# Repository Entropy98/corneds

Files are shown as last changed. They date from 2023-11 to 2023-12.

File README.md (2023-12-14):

# Dependencies
 * PyOCD
 * Pico-SDK
 * gdb-multiarch

# Flashing
1. run `./scripts/flash.sh ./build/corneds_<side>.elf` in the firmware directory
2. Enter `target remote localhost:3333` to connect to started gdb server
**cannot connect with gdb-multiarch --pid argument due to ptrace vulnerability in system**

# To Do
## PCB

## Hardware

## Firmware
 * Tests
   * test debug_print test
     * unclear why uart isn't working

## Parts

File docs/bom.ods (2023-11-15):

Part | Quantity | Price | Total | Link | Total Cost | $30.54
Diodes | 42 | $0.05 | $2.10 | https://www.boardsource.xyz/products/diodesmd
MX Hot Swap Sockets | 42 | $0.15 | $6.30 | https://www.boardsource.xyz/products/MX_Hot_Swap_Sockets
Raspberry Pi Pico | 2 | $5.50 | $11.00 | https://www.amazon.com/Raspberry-Pi-Pico-RP2040-microcontroller/dp/B09437S9X4?th=1
TRRS Connector | 2 | $0.75 | $1.50 | https://www.boardsource.xyz/products/TRRS-connector
TRRS Cable | 1 | $8.00 | $8.00 | https://www.amazon.com/Replacement-Adapter-iPhone-Smartphone-VideoMicro/dp/B07DS2G279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
Reset Switch | 2 | $0.20 | $0.40 | https://www.digikey.com/en/products/detail/c-k/PTS636-SK25F-SMTR-LFS/10071743
SWD Connector | 2 | $0.52 | $1.04 | https://www.digikey.com/en/products/detail/jst-sales-america-inc/SM03B-SRSS-TB/926709
100Ohm 0603 | 2 | $0.10 | $0.20 | https://www.digikey.com/en/products/detail/stackpole-electronics-inc/RMCF0603FT100R/1761113

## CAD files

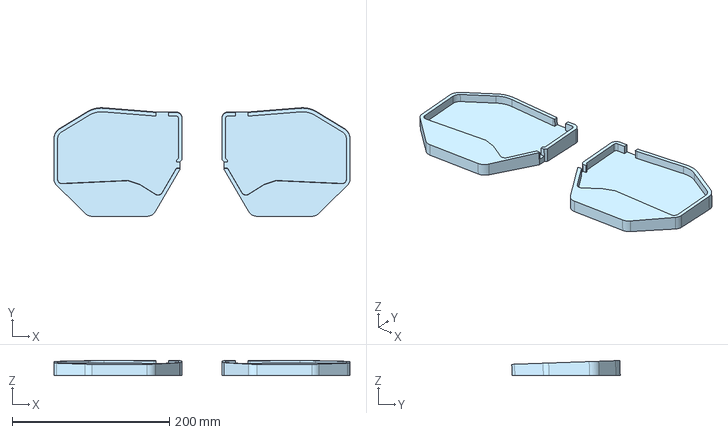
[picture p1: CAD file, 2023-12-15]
hardware/corneds_wooden_base_right.step
375.9 x 137.9 x 19.0 mm

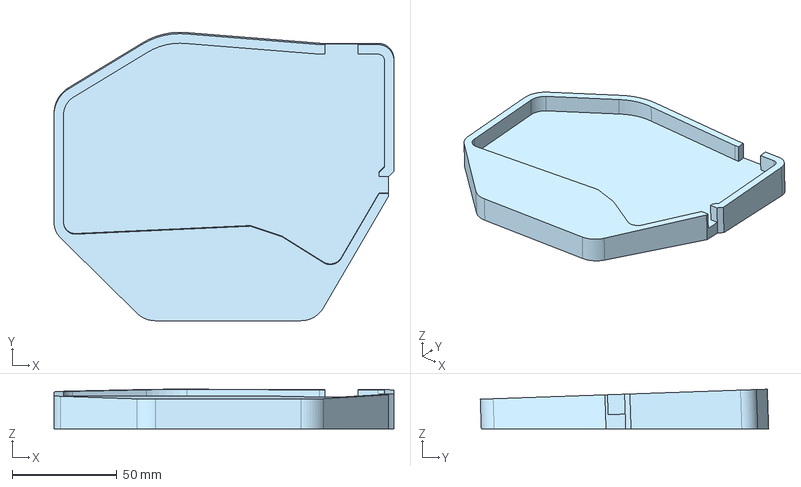
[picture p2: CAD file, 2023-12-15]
hardware/corneds_wooden_base_left.step
162.6 x 137.9 x 19.0 mm

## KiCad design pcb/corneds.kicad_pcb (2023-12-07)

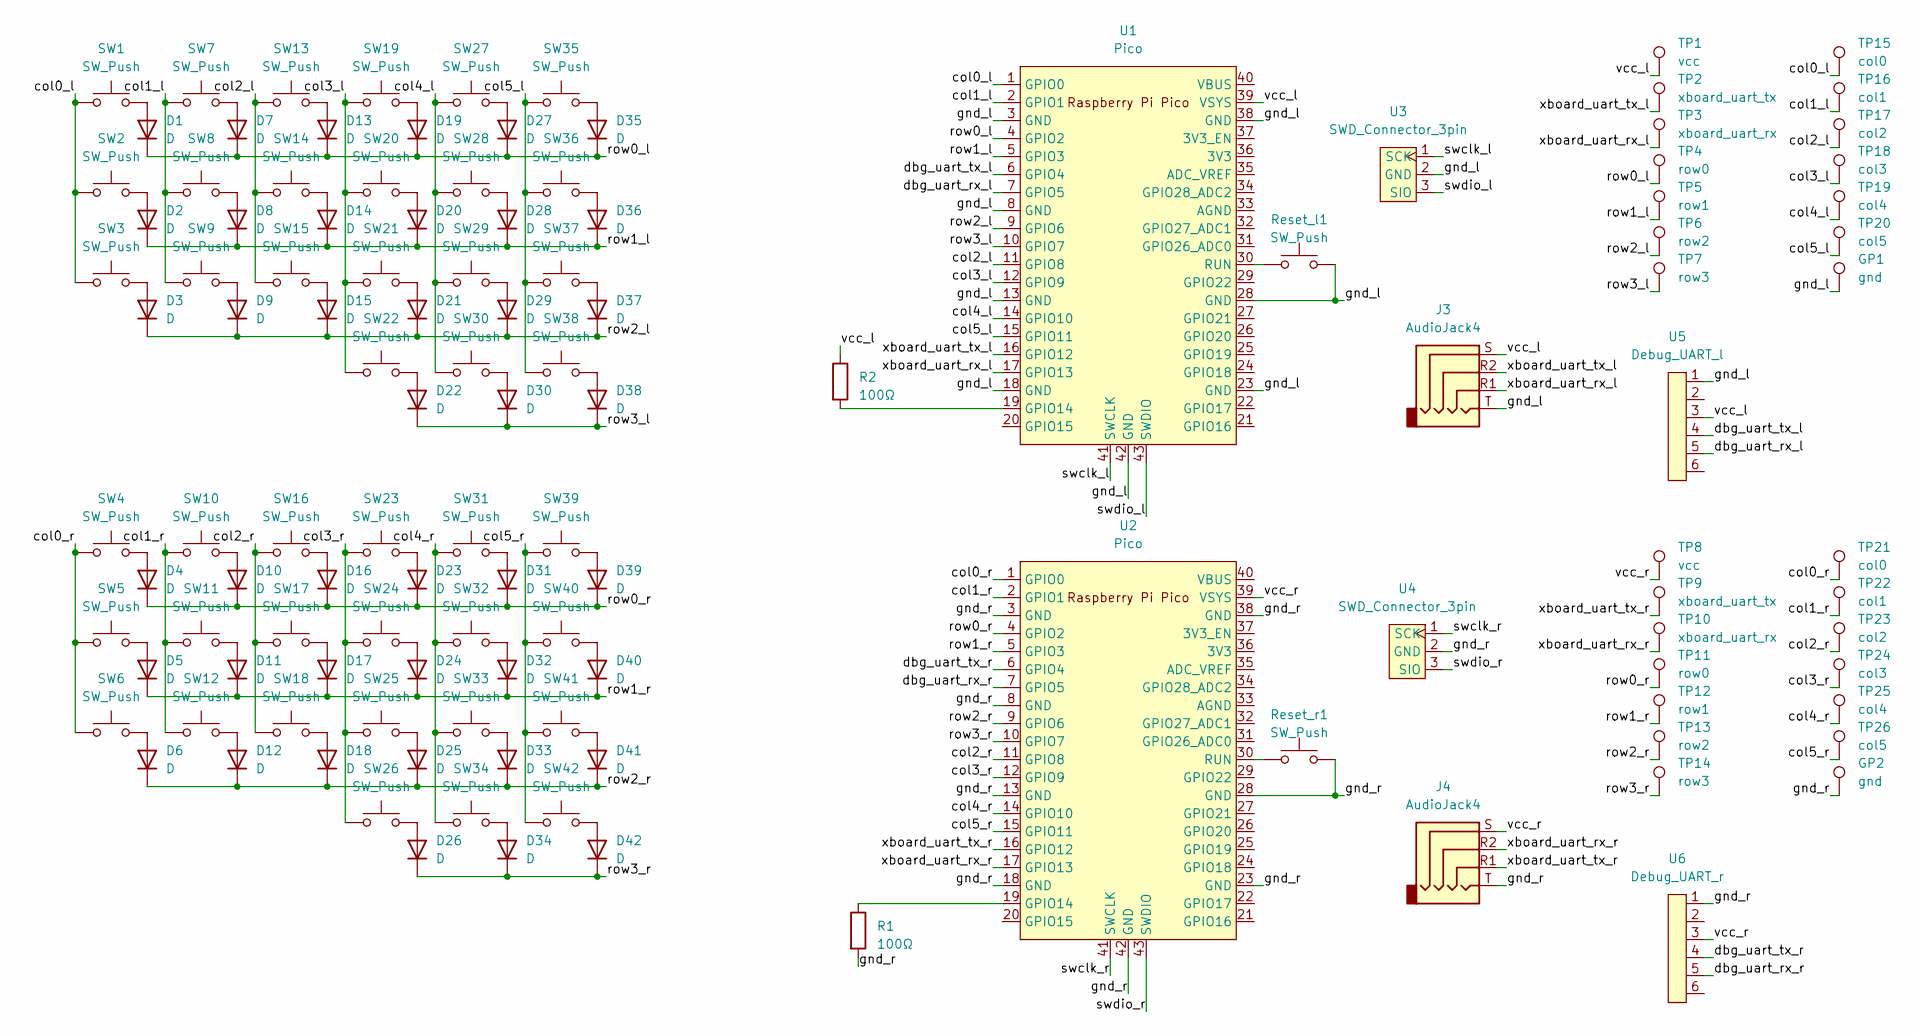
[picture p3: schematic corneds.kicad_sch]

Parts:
D1, D2, D3, D4, D5, D6, D7, D8, D9, D10, D11, D12, D13, D14, D15, D16, D17, D18, D19, D20, D21, D22, D23, D24, D25, D26, D27, D28, D29, D30, D31, D32, D33, D34, D35, D36, D37, D38, D39, D40, D41, D42: D; D_1206_3216Metric
GP1, GP2: gnd; PinHeader_1x01_P2.54mm_Vertical
J3, J4: AudioJack4; Jack_3.5mm_boardsource_TRRS_TH
R1, R2: 100Ω; R_0603_1608Metric
Reset_l1: SW_Push; SW_PTS636_SK25F_SMTR
Reset_r1: SW_Push; SW_PTS636_SK25F_SMTR
SW1, SW2, SW3, SW4, SW5, SW6, SW7, SW8, SW9, SW10, SW11, SW12, SW13, SW14, SW15, SW16, SW17, SW18, SW19, SW20, SW21, SW22, SW23, SW24, SW25, SW26, SW27, SW28, SW29, SW30, SW31, SW32, SW33, SW34, SW35, SW36, SW37, SW38, SW39, SW40, SW41, SW42: SW_Push; Kailh_socket_MX
TP1, TP8: vcc; PinHeader_1x01_P2.54mm_Vertical
TP2, TP9: xboard_uart_tx; PinHeader_1x01_P2.54mm_Vertical
TP3, TP10: xboard_uart_rx; PinHeader_1x01_P2.54mm_Vertical
TP4, TP11: row0; PinHeader_1x01_P2.54mm_Vertical
TP5, TP12: row1; PinHeader_1x01_P2.54mm_Vertical
TP6, TP13: row2; PinHeader_1x01_P2.54mm_Vertical
TP7, TP14: row3; PinHeader_1x01_P2.54mm_Vertical
TP15, TP21: col0; PinHeader_1x01_P2.54mm_Vertical
TP16, TP22: col1; PinHeader_1x01_P2.54mm_Vertical
TP17, TP23: col2; PinHeader_1x01_P2.54mm_Vertical
TP18, TP24: col3; PinHeader_1x01_P2.54mm_Vertical
TP19, TP25: col4; PinHeader_1x01_P2.54mm_Vertical
TP20, TP26: col5; PinHeader_1x01_P2.54mm_Vertical
U1, U2: Pico; RPi_Pico_SMD_TH
U3, U4: SWD_Connector_3pin; SM03B-SRSS-TB
U5: Debug_UART_l; Header_6pin
U6: Debug_UART_r; Header_6pin

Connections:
/col0_l: SW1.1, SW2.1, SW3.1, TP15.1, U1.1 (GPIO0)
/col0_r: SW4.1, SW5.1, SW6.1, TP21.1, U2.1 (GPIO0)
/col1_l: SW7.1, SW8.1, SW9.1, TP16.1, U1.2 (GPIO1)
/col1_r: SW10.1, SW11.1, SW12.1, TP22.1, U2.2 (GPIO1)
/col2_l: SW13.1, SW14.1, SW15.1, TP17.1, U1.11 (GPIO8)
/col2_r: SW16.1, SW17.1, SW18.1, TP23.1, U2.11 (GPIO8)
/col3_l: SW19.1, SW20.1, SW21.1, SW22.1, TP18.1, U1.12 (GPIO9)
/col3_r: SW23.1, SW24.1, SW25.1, SW26.1, TP24.1, U2.12 (GPIO9)
/col4_l: SW27.1, SW28.1, SW29.1, SW30.1, TP19.1, U1.14 (GPIO10)
/col4_r: SW31.1, SW32.1, SW33.1, SW34.1, TP25.1, U2.14 (GPIO10)
/col5_l: SW35.1, SW36.1, SW37.1, SW38.1, TP20.1, U1.15 (GPIO11)
/col5_r: SW39.1, SW40.1, SW41.1, SW42.1, TP26.1, U2.15 (GPIO11)
/dbg_uart_rx_l: U1.7 (GPIO5), U5.5
/dbg_uart_rx_r: U2.7 (GPIO5), U6.5
/dbg_uart_tx_l: U1.6 (GPIO4), U5.4
/dbg_uart_tx_r: U2.6 (GPIO4), U6.4
/gnd_l: GP1.1, J3.T, Reset_l1.2, U1.3 (GND), U1.8 (GND), U1.13 (GND), U1.18 (GND), U1.23 (GND), U1.28 (GND), U1.38 (GND), U1.42 (GND), U3.2 (GND), U5.1
/gnd_r: GP2.1, J4.T, R1.2, Reset_r1.2, U2.3 (GND), U2.8 (GND), U2.13 (GND), U2.18 (GND), U2.23 (GND), U2.28 (GND), U2.38 (GND), U2.42 (GND), U4.2 (GND), U6.1
/row0_l: D1.1 (K), D7.1 (K), D13.1 (K), D19.1 (K), D27.1 (K), D35.1 (K), TP4.1, U1.4 (GPIO2)
/row0_r: D4.1 (K), D10.1 (K), D16.1 (K), D23.1 (K), D31.1 (K), D39.1 (K), TP11.1, U2.4 (GPIO2)
/row1_l: D2.1 (K), D8.1 (K), D14.1 (K), D20.1 (K), D28.1 (K), D36.1 (K), TP5.1, U1.5 (GPIO3)
/row1_r: D5.1 (K), D11.1 (K), D17.1 (K), D24.1 (K), D32.1 (K), D40.1 (K), TP12.1, U2.5 (GPIO3)
/row2_l: D3.1 (K), D9.1 (K), D15.1 (K), D21.1 (K), D29.1 (K), D37.1 (K), TP6.1, U1.9 (GPIO6)
/row2_r: D6.1 (K), D12.1 (K), D18.1 (K), D25.1 (K), D33.1 (K), D41.1 (K), TP13.1, U2.9 (GPIO6)
/row3_l: D22.1 (K), D30.1 (K), D38.1 (K), TP7.1, U1.10 (GPIO7)
/row3_r: D26.1 (K), D34.1 (K), D42.1 (K), TP14.1, U2.10 (GPIO7)
/swclk_l: U1.41 (SWCLK), U3.1 (SCK)
/swclk_r: U2.41 (SWCLK), U4.1 (SCK)
/swdio_l: U1.43 (SWDIO), U3.3 (SIO)
/swdio_r: U2.43 (SWDIO), U4.3 (SIO)
/vcc_l: J3.S, R2.1, TP1.1, U1.39 (VSYS), U5.3
/vcc_r: J4.S, TP8.1, U2.39 (VSYS), U6.3
/xboard_uart_rx_l: J3.R1, TP3.1, U1.17 (GPIO13)
/xboard_uart_rx_r: J4.R2, TP10.1, U2.17 (GPIO13)
/xboard_uart_tx_l: J3.R2, TP2.1, U1.16 (GPIO12)
/xboard_uart_tx_r: J4.R1, TP9.1, U2.16 (GPIO12)
unnamed: D1.2 (A), SW1.2
unnamed: D2.2 (A), SW2.2
unnamed: D3.2 (A), SW3.2
unnamed: D4.2 (A), SW4.2
unnamed: D5.2 (A), SW5.2
unnamed: D6.2 (A), SW6.2
unnamed: D7.2 (A), SW7.2
unnamed: D8.2 (A), SW8.2
unnamed: D9.2 (A), SW9.2
unnamed: D10.2 (A), SW10.2
unnamed: D11.2 (A), SW11.2
unnamed: D12.2 (A), SW12.2
unnamed: D13.2 (A), SW13.2
unnamed: D14.2 (A), SW14.2
unnamed: D15.2 (A), SW15.2
unnamed: D16.2 (A), SW16.2
unnamed: D17.2 (A), SW17.2
unnamed: D18.2 (A), SW18.2
unnamed: D19.2 (A), SW19.2
unnamed: D20.2 (A), SW20.2
unnamed: D21.2 (A), SW21.2
unnamed: D22.2 (A), SW22.2
unnamed: D23.2 (A), SW23.2
unnamed: D24.2 (A), SW24.2
unnamed: D25.2 (A), SW25.2
unnamed: D26.2 (A), SW26.2
unnamed: D27.2 (A), SW27.2
unnamed: D28.2 (A), SW28.2
unnamed: D29.2 (A), SW29.2
unnamed: D30.2 (A), SW30.2
unnamed: D31.2 (A), SW31.2
unnamed: D32.2 (A), SW32.2
unnamed: D33.2 (A), SW33.2
unnamed: D34.2 (A), SW34.2
unnamed: D35.2 (A), SW35.2
unnamed: D36.2 (A), SW36.2
unnamed: D37.2 (A), SW37.2
unnamed: D38.2 (A), SW38.2
unnamed: D39.2 (A), SW39.2
unnamed: D40.2 (A), SW40.2
unnamed: D41.2 (A), SW41.2
unnamed: D42.2 (A), SW42.2
unnamed: R2.2, U1.19 (GPIO14)
unnamed: Reset_l1.1, U1.30 (RUN)
unnamed: R1.1, U2.19 (GPIO14)
unnamed: Reset_r1.1, U2.30 (RUN)

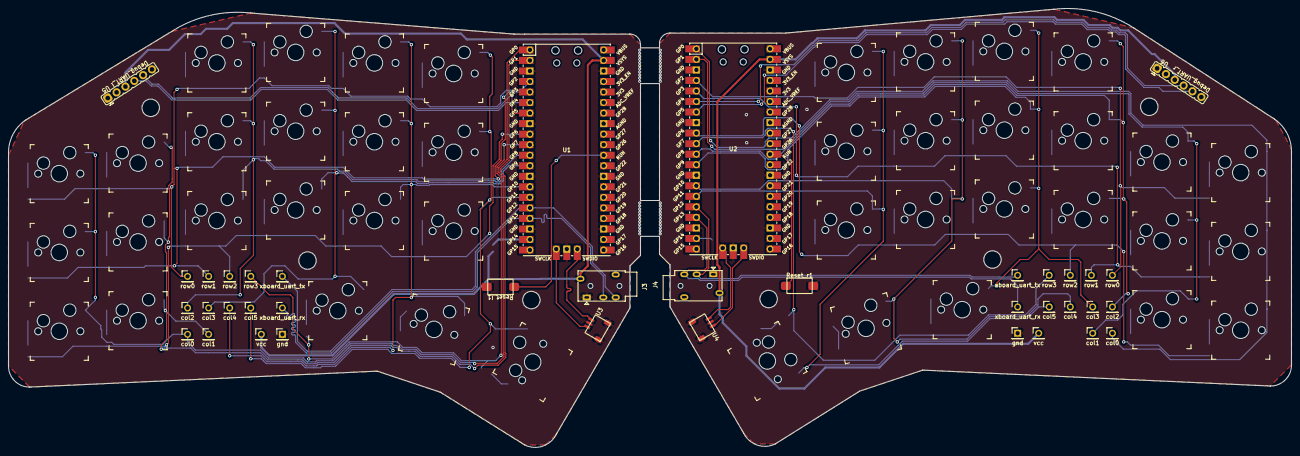
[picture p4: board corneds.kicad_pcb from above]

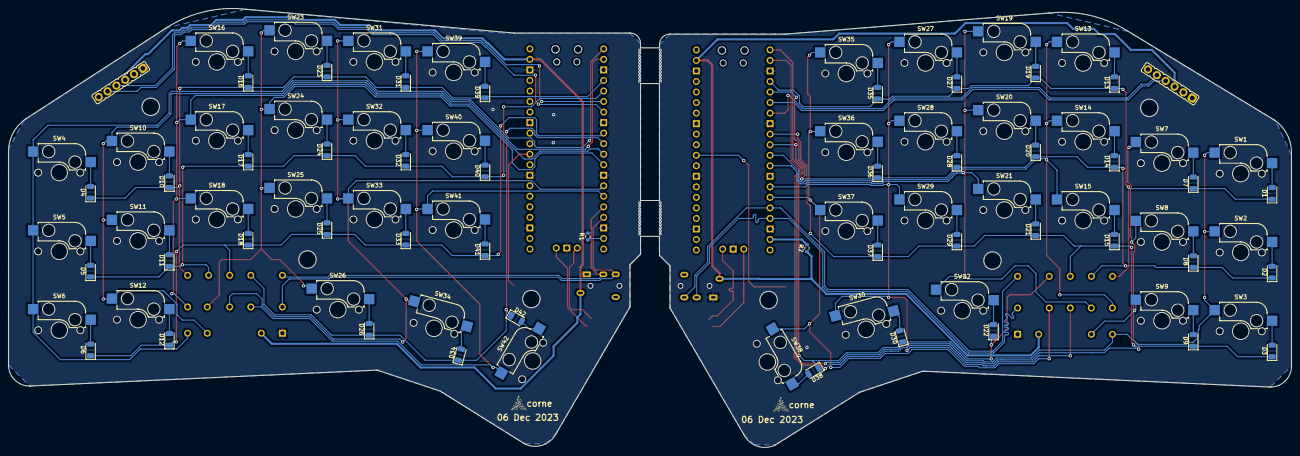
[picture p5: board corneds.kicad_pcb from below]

Board: 2 copper layers, 309.4 x 105.8 mm, 126 parts (44 on the bottom side), 82 nets.

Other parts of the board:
mouse-bite-5mm-slot, mouse-bite-5mm-slot#2: VAL**; mouse-bite-5mm-slot

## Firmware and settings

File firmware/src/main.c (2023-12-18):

/*
 * \file main.c
 * \author Harper Weigle
 * \date Dec 18 2023
 * \brief Firmware for corneDS split 40% keyboard
 */

#include "bsp/board.h"
#include "pico/stdlib.h"
#include "tusb.h"

#include "debug_uart.h"
#include "hid_task.h"
#include "keymap.h"
#include "led_utils.h"
#include "timeslice.h"
#include "usb_descriptors.h"
#include "usb_detect.h"
#include "xboard_comms.h"

int main(void) {
  board_init();

  led_init();
  tusb_init();
  debug_uart_init();

  uint8_t line_state = usb_detected();

  xboard_comms_init(line_state == USB_CONNECTED);
  init_keys(line_state == USB_CONNECTED);

  debug_print("CorneDS 40% Keyboard\n");
  if(line_state == USB_CONNECTED){
    debug_print("Initializing with USB Connected\n");
  }
  else {
    debug_print("Initializing with USB Disconnected\n");
  }

  if(kbd_side_get() == KBDSIDE_RIGHT) {
    debug_print("Initializing as Right Side\n");
  }
  else {
    debug_print("Initializing as Left Side\n");
  }

  while(1) {
    update_time_slices();
    tud_task();

    if(get_ms_slice() != 0) {
      clear_ms_slice();
    }

    if(get_10ms_slice() != 0) {
      poll_keypresses();
      if(line_state == USB_CONNECTED) {
        send_hid_report();
      }
      clear_10ms_slice();
    }

    if(get_100ms_slice() != 0) {
      if(kbd_side_get() == KBDSIDE_RIGHT){
        led_toggle();
      }
      clear_100ms_slice();
    }

    if(get_s_slice() != 0) {
      if(kbd_side_get() == KBDSIDE_LEFT){
        led_toggle();
      }
      clear_s_slice();
    }

  }

  return 0;
}

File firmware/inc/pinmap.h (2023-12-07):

/*
 * \file pinmap.h
 * \author Harper Weigle
 * \date Dec 06 2023
 * \brief mapping of MCU pins
 */

#ifndef _INC_PINMAP_H
#define _INC_PINMAP_H

#define KEYCOL0_PIN  0
#define KEYCOL1_PIN  1

#define KEYROW0_PIN  2
#define KEYROW1_PIN  3

#define DEBUGUARTTX_PIN 4
#define DEBUGUARTRX_PIN 5

#define KEYROW2_PIN  6
#define KEYROW3_PIN  7

#define KEYCOL2_PIN  8
#define KEYCOL3_PIN  9
#define KEYCOL4_PIN  10
#define KEYCOL5_PIN  11

#define XBOARDTX_PIN 12
#define XBOARDRX_PIN 13

#define SIDESELECT_PIN 14

#endif //_INC_PINMAP_H

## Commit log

2023-03-03 still working on layout
    [corneds.kicad_pcb, corneds.kicad_sch]
2023-03-04 no longer committing backups and left side of keyboard almost done placement
    [corneds.kicad_pcb]
2023-03-05 finished left mod key
    [corneds.kicad_pcb]
2023-03-08 finished placing left side
    [corneds.kicad_pcb, corneds.kicad_sch]
2023-03-09 sch updates
    [corneds.kicad_sch]
2023-03-10 working on routing
    [corneds.kicad_pcb]
2023-03-23 ordered version
    [corneds.kicad_pcb, corneds.kicad_sch]
2023-04-15 flattening directory
    [corneds.kicad_pcb, corneds.kicad_sch]
2023-04-15 sdk is included and cmake is setup
    [corneds.kicad_pcb, corneds.kicad_sch]
2023-04-15 led blinky works but there are issues with the time slice architecture. Likely in clearing or setting the flags
    [main.c]
2023-04-20 updated pcb to kicad 7 and started keymap
    [corneds.kicad_pcb, corneds.kicad_sch]
2023-04-22 keys work, macros don't do anything yet, no cross board communication, and preprocessor defines for building different sides aren't working
2023-04-23 started on rev2
    [corneds.kicad_pcb]
2023-04-23 fixed trrs jacks and via shapes
    [corneds.kicad_pcb]
2023-04-25 routed left side, placed 3 more mounting holes but want one more
    [corneds.kicad_pcb, corneds.kicad_sch]
2023-04-26 finished layout on both sides and design front and back plates
    [corneds.kicad_pcb]
2023-04-26 updated date in silk
    [corneds.kicad_pcb]
2023-05-11 usb_detect turns on LED when plugged in but have no tested applying voltage to VBUS directly
2023-05-11 made led utils to have better readability over led states and switched board power to VSYS so we can differentiate right from left based on VBUS. This will run the peripheral board at 4.8V instead of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
    [corneds.kicad_pcb, corneds.kicad_sch]
2023-05-12 started cross board comms but the uart interrupt isn't occuring on the main board
2023-05-18 dbg_uart and xboard_uart were both uart0 so I swapped dbg_uart with cols 0 and 1
    [corneds.kicad_pcb, corneds.kicad_sch]
2023-05-18 changed the pins for xboard comms to be the correct ones
    [xboard_comms.c]
2023-05-27 possibly fixed bug where enter and alt didn't work
    [keymap.c]
2023-09-13 added unit test for print Hello World as a keyboard and fixed issue with latching shift but shift still doesn't work as a key
    [keymap.c]
2023-11-14 added debug prints
2023-11-15 added bill of materials
    [bom.ods]
2023-11-15 test descriptions and fixed shift
    [test_debug_uart.c]
2023-11-22 updated to rev3 of the pcb
    [corneds.kicad_pcb, corneds.kicad_sch]
2023-11-26 added tabs to rev3 and potentially fixed some pin swaps I missed. Also adding alt and gui to key mods
    [corneds.kicad_pcb]
2023-12-07 right side is working but left side needs pins updated
    [corneds.kicad_pcb, corneds.kicad_sch]
2023-12-07 fixed silk
    [corneds.kicad_pcb]
2023-12-14 updated front plate and made 3D models to CNC wooden base plate
    [corneds_wooden_base_left.step, corneds_wooden_base_right.step]
2023-12-15 finished up hardware
    [corneds_wooden_base_left.step, corneds_wooden_base_right.step]
2023-12-15 shrunk mounting holes
2023-12-18 changed time slices to use pico-sdk us function and pushing key presses on change rather than whenever polled high
2023-12-18 made keypress implementation but might have actually figured out what was wrong
    [keymap.c, main.c]
